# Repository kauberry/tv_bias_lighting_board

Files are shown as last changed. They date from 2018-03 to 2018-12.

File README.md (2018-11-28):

## Controller for Television Bias Lighting with LED strips ##

### Background ###
I wanted to have a bias lighting system for my wall mounted TV's such that the lights would be controlled by the TV itself through one of its built-in USB ports, but still be actually powered from a 12v power adapter, so as not to overrun the USB port's current ratings.

The whole show is being run by an ATTiny85 AVR chip that is listening to the USB port on the TV (through an optocoupler), waiting for the set to power up/down, and fading the lights up or down as appropriate.

### Availability ###
I've made the project available on OSHPark, for anyone who is interested. The version up right now is currently untested in physical form, so order at your own risk. Once I get my boards back, I'll update.

https://oshpark.com/shared_projects/4CxVxJLe

#### Bill of Materials
Quantity | Item                         | Part Number / Identifier
:--------: | -------------------------- | -------------------
  1    | ATTiny85 8-pin SOIC AVR Chip | ATTiny85
  1    | 5.5mm Power Jack             | DCJ0202
  1    | MicroUSB SMD Jack            | *
  1    | 2 Position Terminal Block    | *
  3    | 10kΩ 1206 Chip Resistor      | *
  1    | 1kΩ 1206 Chip Resistor       | *
  1    | 150Ω 1206 Chip Resistor      | *
  1    | 0.1µF 1206 Chip Capacitor    | *
  1    | SMA-form factor Schottky Diode | *
  1    | Single-channel Optocoupler   | Sharp EL817
  1    | LDO 5V Regulator (SOT-223)   | *
  1    | N-channel MosFET Transistor  | IRLML2502

#### Prototype Board Images
These are the pre-production renders of the board proper, straight from [OSH Park](http://oshpark.com)

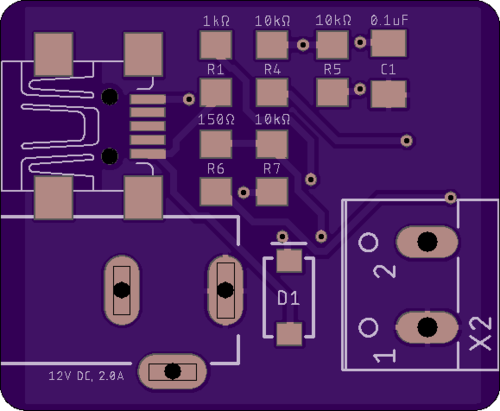
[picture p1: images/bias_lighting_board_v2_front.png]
Prototype Board Front Image


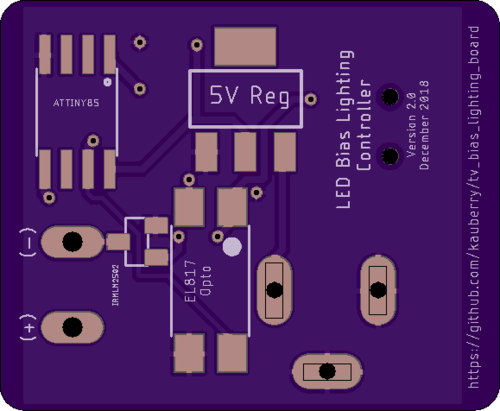
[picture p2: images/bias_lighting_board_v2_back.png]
Prototype Board Back Image


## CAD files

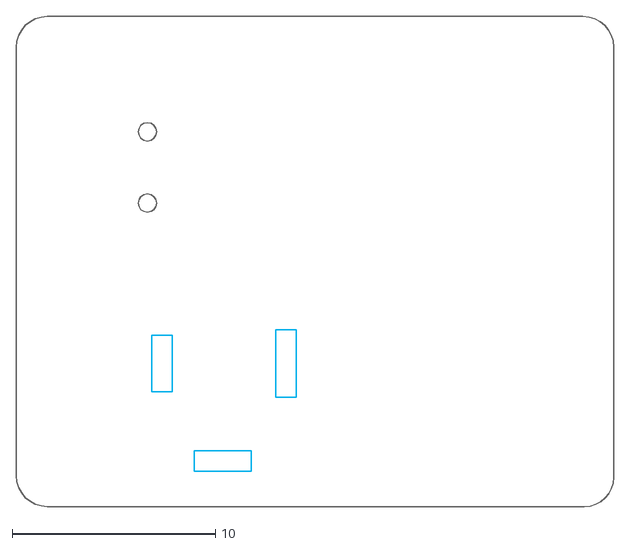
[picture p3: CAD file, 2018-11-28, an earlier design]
hardware/schematics/version 2.0/Bias_Lighting_Controller_Schematic.dxf
29.4 x 24.1

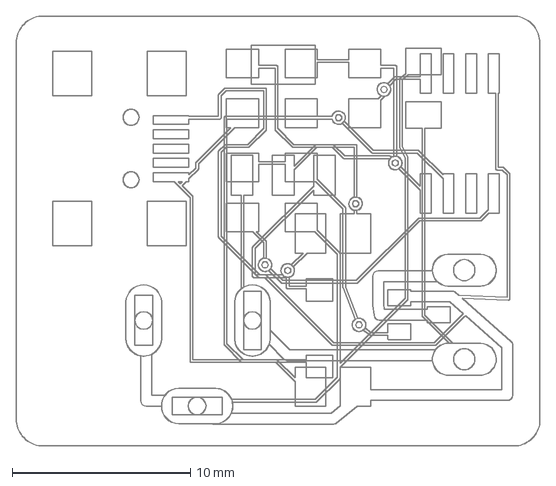
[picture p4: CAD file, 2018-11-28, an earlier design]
hardware/schematics/version 2.0/images/tv_bias_board_front_holes.dxf
29.4 x 24.1 mm

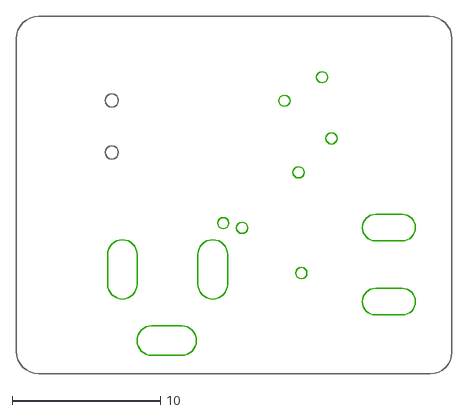
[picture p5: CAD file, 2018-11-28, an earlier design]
hardware/schematics/version 2.0/images/tv_bias_board_drills.dxf
29.4 x 24.1

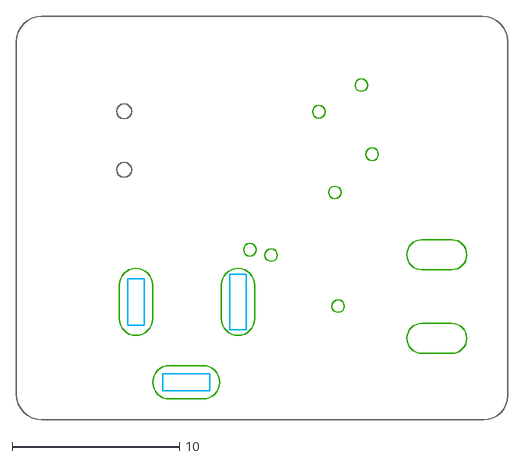
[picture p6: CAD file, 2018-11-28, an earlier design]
hardware/schematics/version 2.0/images/tv_bias_board_holes.dxf
29.4 x 24.1

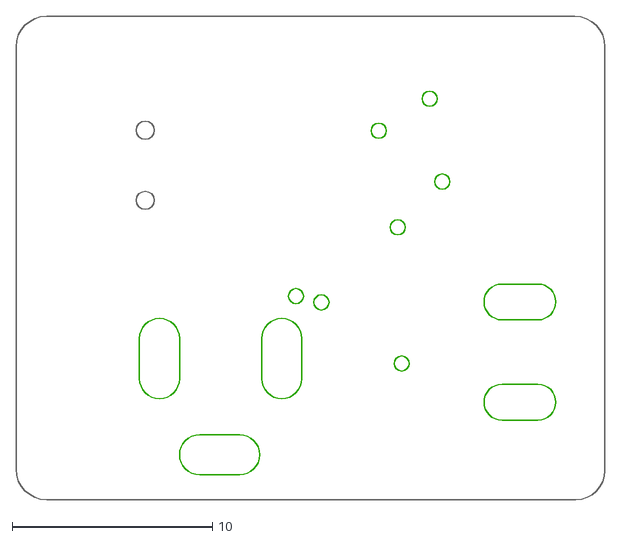
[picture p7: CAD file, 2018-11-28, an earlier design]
hardware/schematics/version 2.0/images/tv_bias_board_drills_ww.dxf
29.4 x 24.1

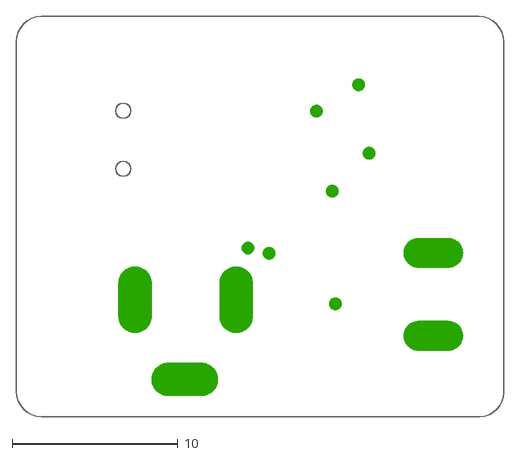
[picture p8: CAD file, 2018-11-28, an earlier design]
hardware/schematics/version 2.0/images/tv_bias_board_drills_fa.dxf
29.4 x 24.1

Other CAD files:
hardware/schematics/version 2.0/images/attiny85.skp
hardware/schematics/version 2.0/images/dc_jack.skp
hardware/schematics/version 2.0/images/dc_jack_2.skp
hardware/schematics/version 2.0/images/micro_usb.skp
hardware/schematics/version 2.0/images/mini_usb.skp
hardware/schematics/version 2.0/images/soic-8.skp
hardware/schematics/version 2.0/images/sot-223.skp
hardware/schematics/version 2.0/images/terminal_block.skp
hardware/schematics/version 2.0/images/terminal_block_2.skp
hardware/schematics/version 2.0/images/tv_bias_board.skp
hardware/schematics/version 2.0/images/tv_bias_board_2.skp

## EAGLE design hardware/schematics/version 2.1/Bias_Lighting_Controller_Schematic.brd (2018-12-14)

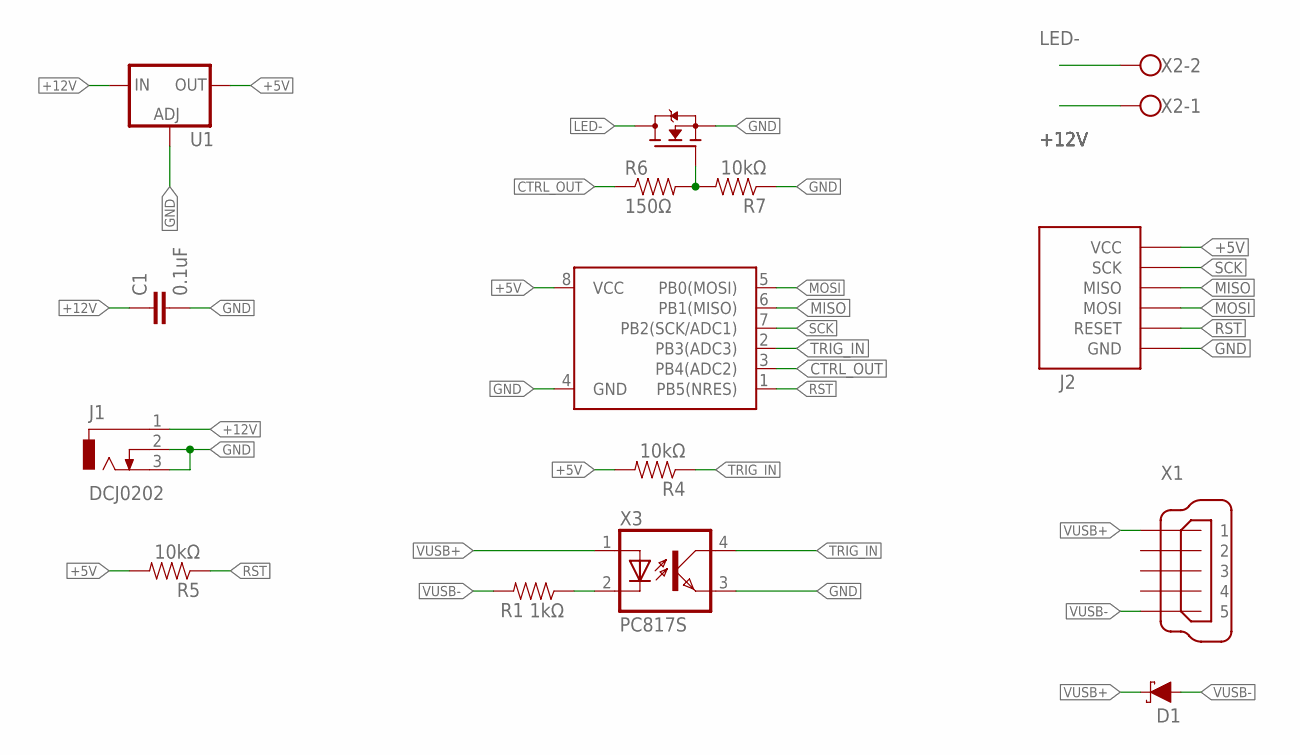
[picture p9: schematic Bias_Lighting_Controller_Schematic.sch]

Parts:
ATTINY85: ATTINY45; SO08-EIAJ
C1: 0.1uF; C1206K
D1: DIODE-SCHOTTKY-SS14; SMA-DIODE
IRF740_MOSFET1: MOSFET-N-SOT23; SOT23
J1: DCJ0202
J2: AVR_MICRO_ICP
R1: 1kΩ; 1206
R4, R5, R7: 10kΩ; 1206
R6: 150Ω; 1206
U1: V_REG_317SMD; SOT223
X1: MINI-USB-UX60-MB-5ST; UX60-MB-5ST
X2: W237-102
X3: PC817S; PC817SMT

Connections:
+5V: ATTINY85.8 (VCC), J2.VCC, R4.2, R5.2, U1.2 (OUT)
+12V: C1.1, J1.1, U1.3 (IN), X2.1
CTRL_OUT: ATTINY85.3 (PB4(ADC2)), R6.1
GND: ATTINY85.4 (GND), C1.2, IRF740_MOSFET1.2 (S), J1.2, J1.3, J2.GND, R7.1, U1.1 (ADJ), X3.3 (EMIT)
LED-: IRF740_MOSFET1.3 (D), X2.2
MISO: ATTINY85.6 (PB1(MISO)), J2.MISO
MOSI: ATTINY85.5 (PB0(MOSI)), J2.MOSI
unnamed: IRF740_MOSFET1.1 (G), R6.2, R7.2
RST: ATTINY85.1 (PB5(NRES)), J2.RESET, R5.1
SCK: ATTINY85.7 (PB2(SCK/ADC1)), J2.SCK
TRIG-: R1.1, X3.2 (C)
TRIG_IN: ATTINY85.2 (PB3(ADC3)), R4.1, X3.4 (COL)
VUSB+: D1.C, X1.1, X3.1 (A)
VUSB-: D1.A, R1.2, X1.5

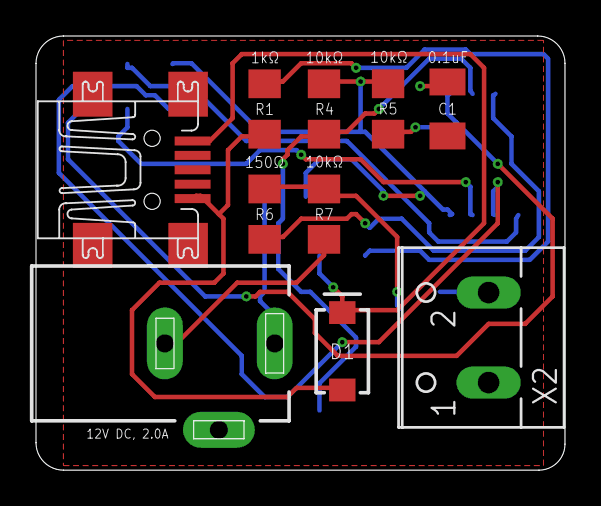
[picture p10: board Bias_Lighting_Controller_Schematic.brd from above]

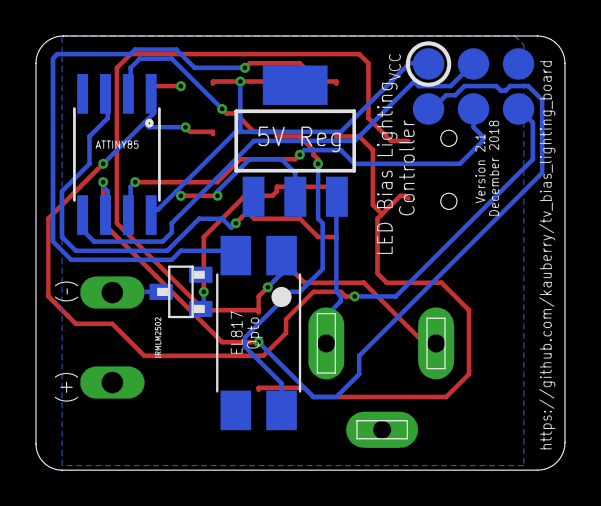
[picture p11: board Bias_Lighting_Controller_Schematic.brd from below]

Board: 2 copper layers, 29.4 x 24.1 mm, 15 parts (5 on the bottom side), 14 nets.

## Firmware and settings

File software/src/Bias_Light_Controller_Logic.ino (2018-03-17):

#include "avr/interrupt.h"

int sensePin = 2;       //pin to sense system turn on
int controlPin = 0;    //output pin for the mosfet
volatile int reqLightLevel = 0;
int currLightLevel = 0;
volatile int powerState = LOW;
int maxLightLevel = 255;
volatile int change = LOW;

void setup() {
        // put your setup code here, to run once:
        pinMode(sensePin, INPUT);
        powerState = digitalRead(sensePin);
        analogWrite(controlPin, currLightLevel);
        attachInterrupt(0, switch_on, CHANGE);

}

void loop() {
        if(reqLightLevel > currLightLevel) {
                delay(4000);
                for(int f = 0; f < maxLightLevel; f += 1) {
                        analogWrite(controlPin, f);
                        delay(10);
                }
        }else if(reqLightLevel < currLightLevel) {
                for(int f = maxLightLevel; f >= 0; f -= 1) {
                        analogWrite(controlPin, f);
                        delay(5);
                }
        }
        change = LOW;
        currLightLevel = reqLightLevel;
        delay(10);
}

void switch_on(){
        powerState = digitalRead(sensePin);
        if(powerState == LOW) {
                reqLightLevel = 0;
        }else{
                reqLightLevel = maxLightLevel;
        }
        change = HIGH;
}

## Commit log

2018-11-28 Updated the board design to use more SMD components
    [Bias_Lighting_Controller_Schematic.brd, Bias_Lighting_Controller_Schematic.dxf, Bias_Lighting_Controller_Schematic.sch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]
2018-11-28 Adding documentation and labeled board files
    [Bias_Lighting_Controller_Schematic.brd]
2018-12-14 Adding AVR-ISP pads to existing board for easier programming
    [Bias_Lighting_Controller_Schematic.brd, Bias_Lighting_Controller_Schematic.sch]

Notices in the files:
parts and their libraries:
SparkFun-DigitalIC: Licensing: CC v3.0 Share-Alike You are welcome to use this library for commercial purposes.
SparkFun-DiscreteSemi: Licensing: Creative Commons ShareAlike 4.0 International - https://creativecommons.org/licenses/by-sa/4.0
